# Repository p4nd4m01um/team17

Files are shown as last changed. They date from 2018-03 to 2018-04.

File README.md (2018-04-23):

dei cing 2
========

## Motivation
In the winters of Glasgow, our team found roads always icy and slippery. Some people slip on roads because of ice and snow. So we decided to construct a system to prevent these accidents.
  
## Target
This project aims to prevent the formation of ice or snow by using brine as the anti-icing agent. Utilising the humidity and temperature sensor to detect the environmental conditions, the sprinkler spreads the brine water which is controlled by Raspberry Pi. IR sensor is used to detect people and animals. When it detects people, the sprinkler turns off.  

## Setup
<p align="center">
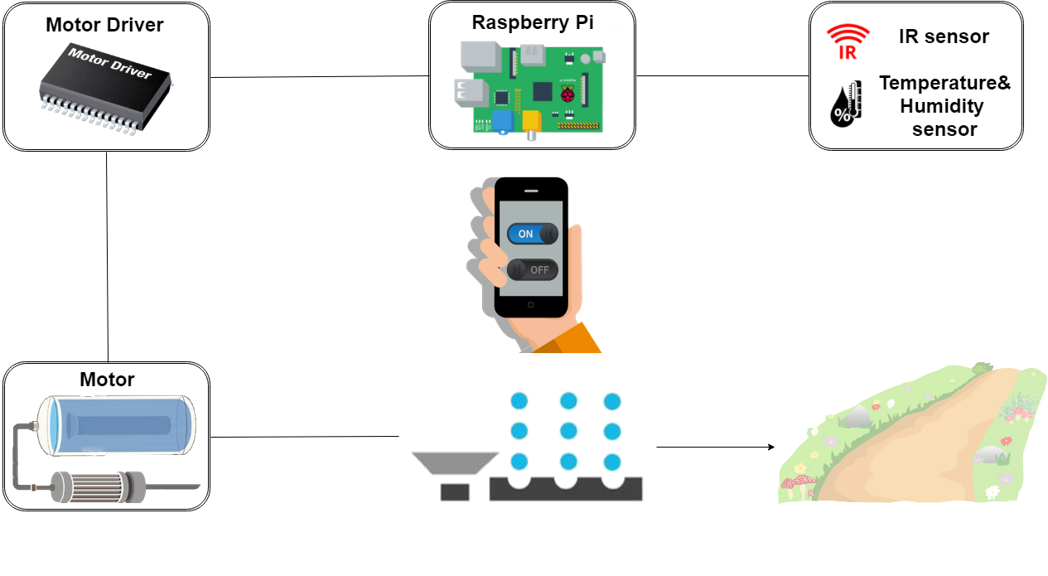
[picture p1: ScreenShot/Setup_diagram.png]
 
</p>

## Flow Diagram
<p align="center">
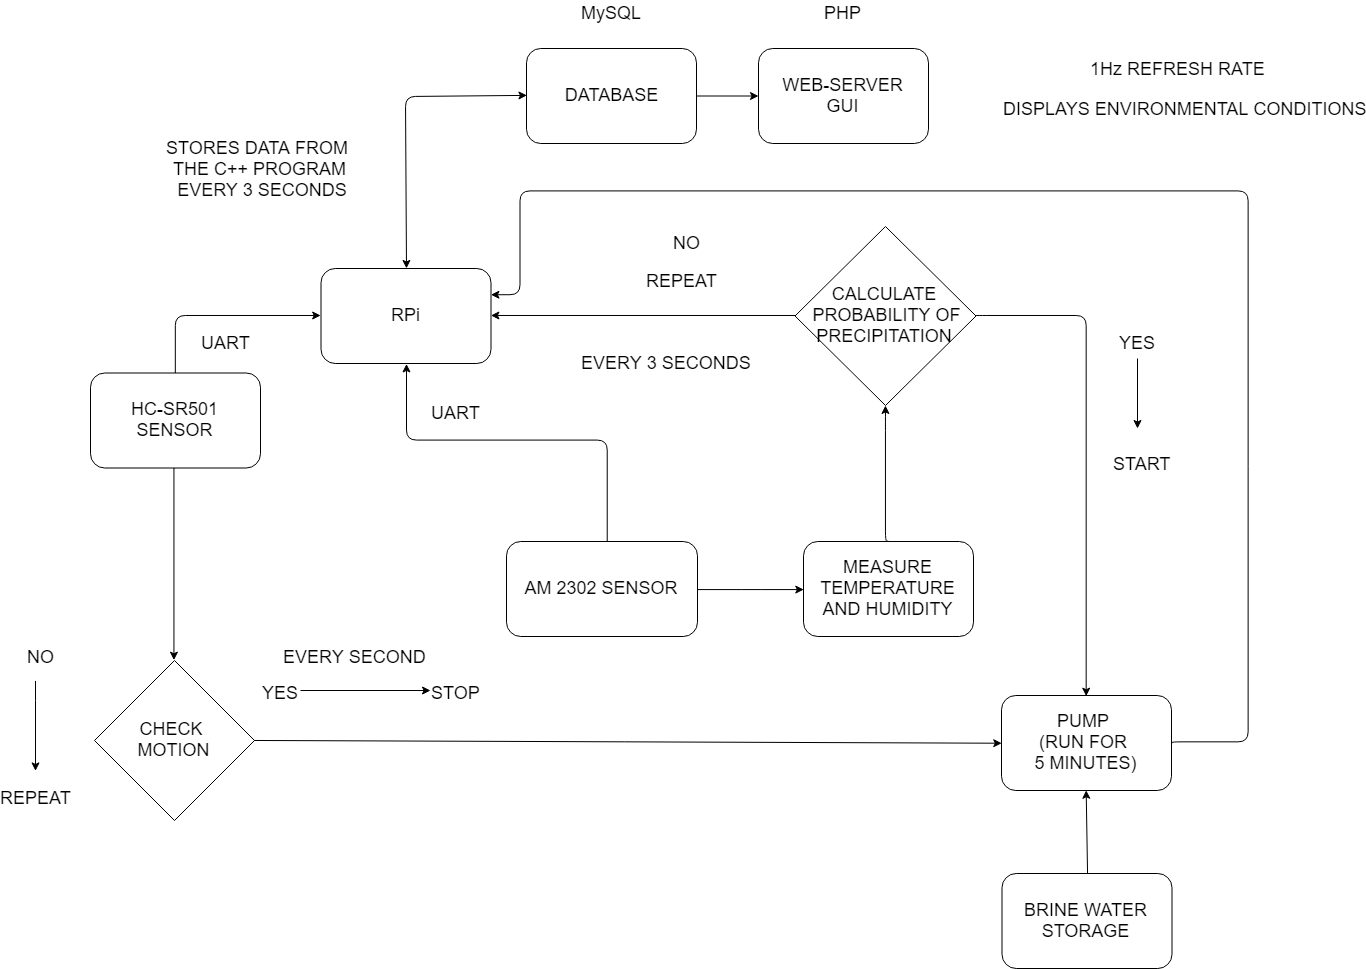
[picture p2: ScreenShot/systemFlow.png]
 
  
***

## Components

**1. _IR sensor: HC-SR501 PIR Motion Detector_**  
- Voltage: 5V – 20V  
- Power Consumption: 65mA  
- TTL output: 3.3V, 0V  
- Lock time: 0.2 sec  
- Trigger methods: L – disable repeat trigger, H enable repeat trigger  
- Sensing range: less than 120 degree, within 7 meters  
- Temperature: – 15°C ~ +70°C  
- Dimension: 32*24 mm, distance between screw 28mm, M2, Lens dimension in diameter: 23mm

<p align="center">
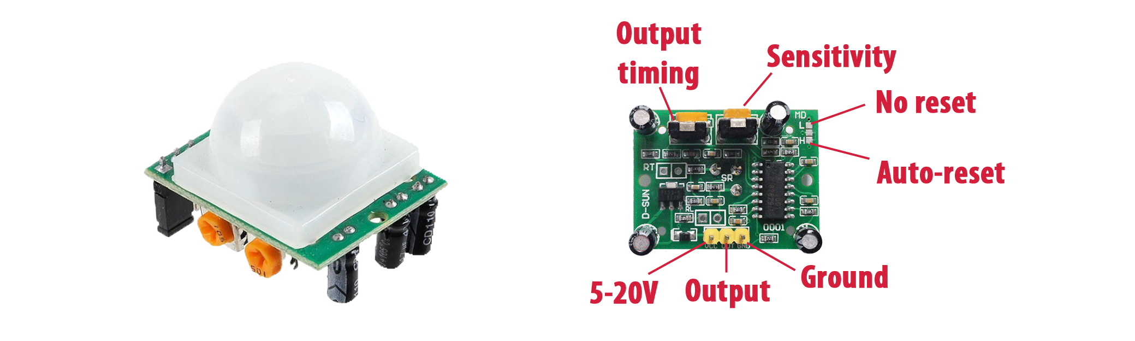
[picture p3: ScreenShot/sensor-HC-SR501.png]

</p>

**2. _Humidity and temperature sensor: DHT22(AM2302)_**
- Low cost  
- 3 to 5V power and I/O  
- 2.5mA max current use during conversion (while requesting data)  
- Good for 0-100% humidity readings with 2-5% accuracy  
- Good for -40°C to 80°C temperature readings ±0.5°C accuracy  
- No more than 0.5 Hz sampling rate (once every 2 seconds)  
- Single-bus data is used for communication between MCU and DHT22, it costs 5ms for single time
communication.  

<p align="center">
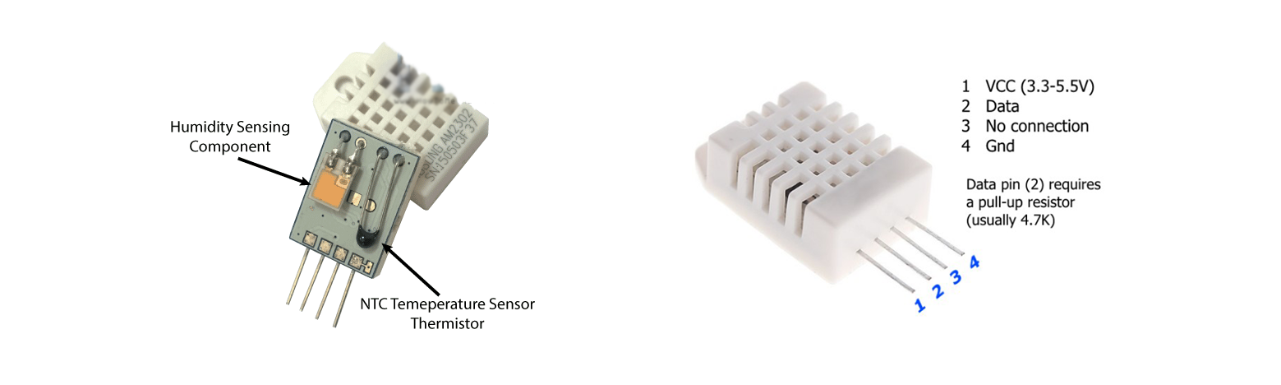
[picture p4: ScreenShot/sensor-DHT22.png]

</p>

**3. _Brushless DC Motor Pump Decdeal QR50E_**
- Low cost and Versatile
- 12V 5W Rating
- 280l/H pump quantity
- can handle different types of solutions including salt water (brine) and oil at various temparatures

<p align="center">
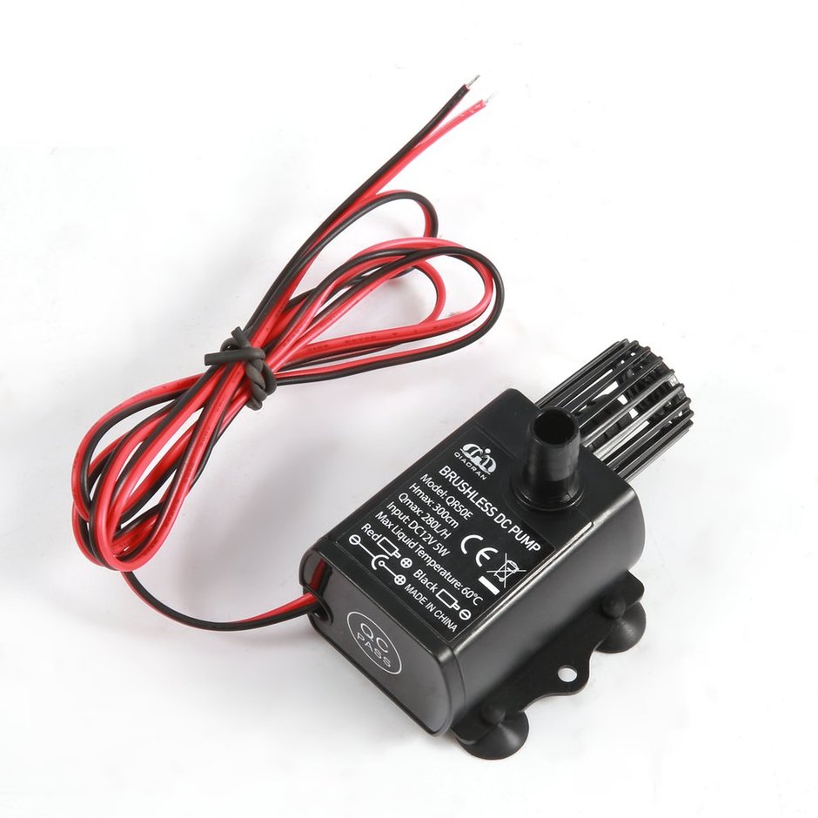
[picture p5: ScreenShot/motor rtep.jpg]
  
</p>

## How to implement code  
1. Clone the repository.
2. Copy the Code/html to /var/www/html
3. In the Code folder, the main file can be executed.
4. If you changed the input/output pin number, you can use CMake to rebuild the main file.
5. Open browser enter the address of raspberryPi to access the user interface. 

## More information in [WIKI](https://github.com/p4nd4m01um/team17/wiki)  
## Criteria for assessment： [Criteria](https://github.com/p4nd4m01um/team17/blob/master/Criteria.md)
  
# YouTube Video:
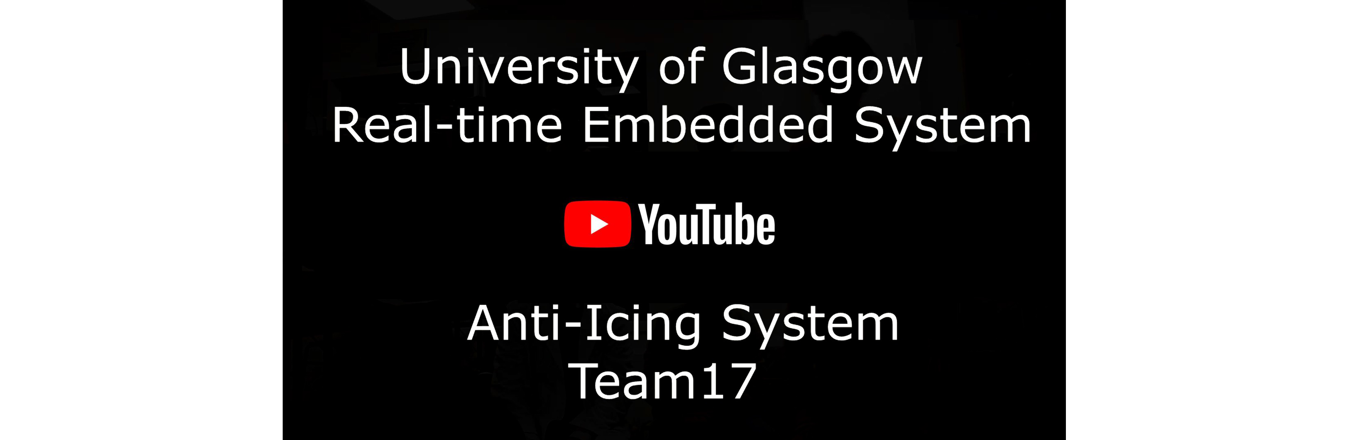
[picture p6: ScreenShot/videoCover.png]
(http://www.youtube.com/watch?v=QaHXD64GoVk "")


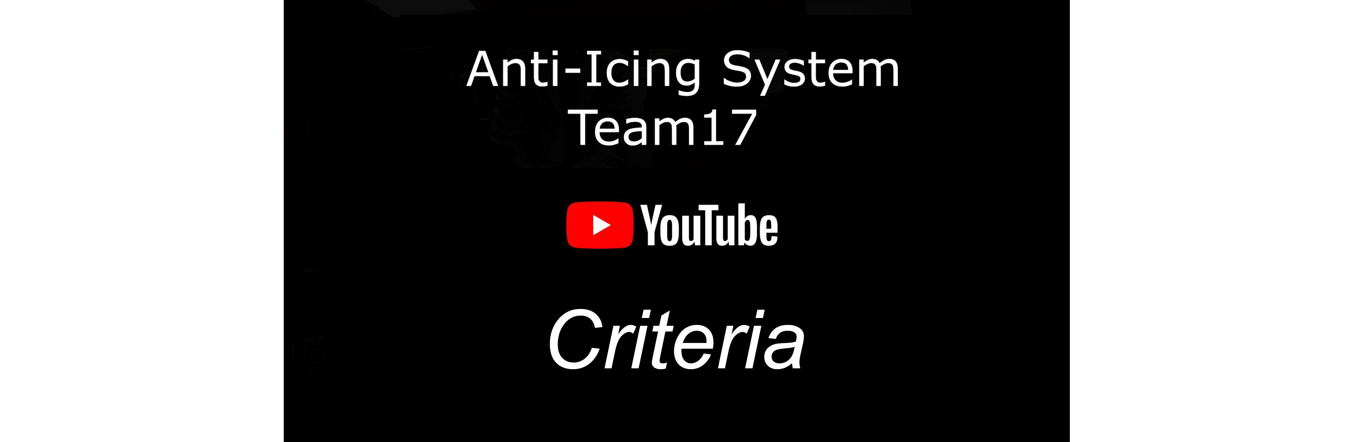
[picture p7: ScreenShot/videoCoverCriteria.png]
(http://www.youtube.com/watch?v=q8ZnzTlgLoI "")


## University of Glasgow

Course name Real Time Embedded Programming, in association with University of Glasgow.  
Course convener: Dr. Bernd Porr

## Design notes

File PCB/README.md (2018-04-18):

# PCB description  

## Schematic and PCB   
We selected Orcad capture and PCB editor to draw the PCB. 
#### sensors circuit:   
The original file of the [schematic](https://github.com/p4nd4m01um/team17/blob/master/PCB/Sensor%20circuit.zip).  Please open this file by Orcad Capture.  
The original file of the [PCB](https://github.com/p4nd4m01um/team17/blob/master/PCB/Circuit%20for%20sensors.brd). Please open this file by PCB Editor.   
  
### Here is the schematic of sensors circuit. 16 pins are enough for our project, so we only used a header with 16 Pins.   
J2 is for PIR sensor  
J3 is for humidity&temperature sensor   
J4 is for GPIO  
R1 and R2 are the pull-up resistors   
D1 LED is for the motor test. This signal is used to control motor.  
D2 LED is for observation. It will show if the circuit is working.    
sensor circuit    
  
### The PCB layout is shown in the next figure.  
sensor pcb layout     
    
### Here is the pdf file for fabrication. This one is the top layer.  
sensor pcb top      
  
### Here is the bottom layer.  
sensor pcb    
  
### The real view  

</p>

---    
### Schematic and PCB for motor drive  

#### motor control circuit:  
The original file of the [schematic](https://github.com/p4nd4m01um/team17/blob/master/PCB/Motor%20control%20circuit.zip).  Please open this file by Orcad Capture.  
The original file of the [PCB](https://github.com/p4nd4m01um/team17/blob/master/PCB/Motot%20control.brd). Please open this file by PCB Editor.  
### Here is the Schematic of Motor driver circuit. 
J1 is for Power source.  
J2 is for Motor.  
J3 is for Control signal that comes from the GPIO.  
J4 is for switch.  
Q1 is to control the motor.  
D2 LED is to check if the circuit works properly.  
motor circuit  

### The PCB layout is shown in the next figure.  
motor pcb layout  

### Here is the pdf file for fabrication. This one is the top layer.  
motor pcb top  
  
### This one is the bottom layer.  
motor pcb bottom  
  
### The real view  

</p>

  #### PCB Artwork  
   PCB Artwork in the circuit designing process refers to the planning and placing of electrical traces and via holes to connect every component mounted on the board with each other.  
   PCB Artwork rules/guidelines is used as a base for the circuit design to facilitate a standard design and manufacturing procedures.
   this file named as ``` art_parm.txt ``` .
    
  #### PCB NC  
   Named as ``` nc_param.txt ```.  
     
  #### IPC2581  
  IPC-2581 is a generic standard for printed circuit board and assembly manufacturing description data and transfer methodology.  
  This file named as ``` ipc2581.txt```.

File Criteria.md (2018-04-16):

# Criteria

**_1. Assessment of responsiveness of the application in the context of the task._**
 
Since the environmental changes aren’t very drastic, slow response is perfectly acceptable. Our system does not have any major latency (0.022 seconds to 5 ms approx.) impeding the purpose of the tasks it has to perform. Thus, proving to be quite an effective solution.
 
_**2. Overall latency between the physical event and output**_

Approximately 3 to 4 second delay between the web server and physical event is found to exist. Since the speed of the response doesn’t take a high precedence in the application of our system, we can easily work with the existing latency in the system. It must also be noted that the responsive action is instantaneous, whereas the display of information on the web server has latency. 

The sensors have a processing latency of about 0.022 seconds to 5ms. Thus, it does not affect the performance of the system.

_**3. What is the sampling rate?**_
 
We use 2 sensors. 

* PIR sensor: which has a sampling rate of 1 second    
* Temperature & Humidity sensor: sampling rate of 3 seconds

The sampling of the data from the C++ program to the mySQL database occurs every 3 seconds

The PHP web server reads data from the database every second

_**4. Bus protocols:**_
 
The sensors come with a support for various bus protocols. But, we prefer to use UART (Universal Asynchronous Receiver-Transmitter) as we can use 1 Data bus to achieve our requirements and also, due to the simplicity in programming it. The 40-bit data response signal from Temperature sensor is given in the wiki.

Single-bus data is used for communication between RPI and DHT22, it costs 5ms for single time communication. This is a latency caused due to data processing.
 
_**5. How many channels?**_

A total number of 3 channels were ussed for the project. Namely:
* Motor
* PIR sensor
* Temperature and Humidity sensor
 
_**6. Low level implementation:**_

Userspace is used. Because:

* To implement GUI (Web-Server).
* Coding is easier.
* Fast response of the system is not an issue.
 
_**7. Data flow is provided in the detailed control flow graph section in the wiki.**_

[Detailed Control Flow Graph of the System](https://github.com/p4nd4m01um/team17/wiki/Detailed-Control-Flow-Graph-of-the-System)

_**8. Buffering of Data: How many samples?**_

We do not use a buffer as it is not necessary for a project of this scale. However, we use a database to store the obtained data from the sensors before the website reads it. The website reads the stored data every 3 seconds from the MySQL database.

_**9. Buffering:**_

No buffer is used, as we do not have a large amount of data that needs to undergo post-processing procedures and data trend analysis. However, since data from the temperature and humidity sensor is a string of 40 bits, it will only output temperature and humidity value after serially processing the entire string of 40 bits of data. Thus, we have added a timer and timed the latency resulting from it.

Latency due to buffering:
* No latency is resulted from the sensor buffer. 
* When a timer is added and the latency is timed, a latency of 0.022 seconds to 5 ms  was resulted from the temperature and humidity sensor.
 
_**10. Post Processing of data:**_

No latency due to post-processing is resulted as we are using only BLDC motor pump as an output, whose response is instantaneous. thus N/A.
 
_**11. How many threads are used:**_

4 threads have been used.
* Main works on one thread.
* Both the sensors work on their own independent threads.
* The web server runs on its own thread.

_**12. GUI:**_
 
The web-server is written in PHP using jQuery and Ajax which is short for asynchronous JavaScript and XML. It reads data from the database every second (which doubles up as the refresh rate of the website).  
 
_**13. Structure of the software:**_

The software structure has a low coupling design. We are using MySQL database as a medium for data storing and reading. One class called MyDB which manipulates MySql database by using SQL syntax. Another class called Sensor which involves relevant variables and reading functionalities for Temperature and Humidity sensor and PIR sensor. The main function calls the sensor functions for retrieving data and then stores the data into the database. The web server read the data from Mysql database. The task of controlling the motor pump is accomplished through PHP(web server).

_**14. Roles in the team:**_
 
_Revanth Kailashnath:_
* Github maintenance and updates including licenses, readme, wiki and code
* Technical content writing including criteria of assessment
* Procuring Hardware and sensor selection
* Motor control circuit, PCB designs and soldering
* Hardware implementation
* Mathematical equation for finding RHthreshold
* Package Version numbering and release
* Release strategy formulation
* Publications in various electronic blogs and websites including hackaday, hackster, instructables, reddit/r/diy

_Jinyu Cao:_
* Github Readme.md
* Procuring Hardware and sensor selection
* sub function for sensors
* PCB designs for sensors and motor
* PCB fabrication, soldering and test
* Unit test 
* Videography

_Hao Ding:_
* Code of Temperature & Humidity sensor
* Code of IR sensor
* Code of Snow calculation
* Code of MySql connection
* Building MySql database
* Building Web server
* Php code for data connection
* User interface design
* Applying domain name for public accessibility
* WIKI layout
* Video editing

_**15. Time allocation:**_
 
* Software: 2 months
* Hardware: 1 month
* Mechanical setup:10 days
 
_**16. Version Control Software and numbering of releases/ milestones:**_

Git as it is free. GitHub has a wide popularity in the technogeek community. It is easy to log, maintain and very efficient to use.
A project with only one branch(master) was used with accomodating and sensible distribution of various tasks among the team members. V 1.0 was released on the 16th of April, 2018 to mark the milestone of initial release of the product. later versions will be released based on the performance and iff tweaking is necessary.

_**17. Release strategy:**_

Publication in various social media and mainstream electronic websites, including:

* Hackster:  https://www.hackster.io/vant4u/anti-icing-system-440a41
* Instructables:  https://www.instructables.com/id/Anti-Icing-System/
* reddit/r/diy:  https://www.reddit.com/r/raspberry_pi/comments/8coow3/antiicing_system_using_raspberry_pi/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
* Submitted the project to hackaday (waiting for them to revert back)
* create YouTube videos: 	https://www.youtube.com/watch?v=QaHXD64GoVk  
  				https://www.youtube.com/watch?v=q8ZnzTlgLoI

_**18. Measurement of success:**_

We will consider the project to be a success if it can prevent the formation of ice (precipitation) on pavements. Seeing as its accomplished this mission, the contraption can be declared to be a success. 
We will update you the success story by the end of the course duration.

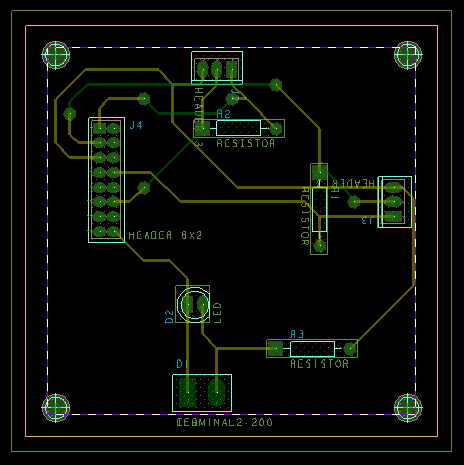
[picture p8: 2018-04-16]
ScreenShot/schematic_2.PNG

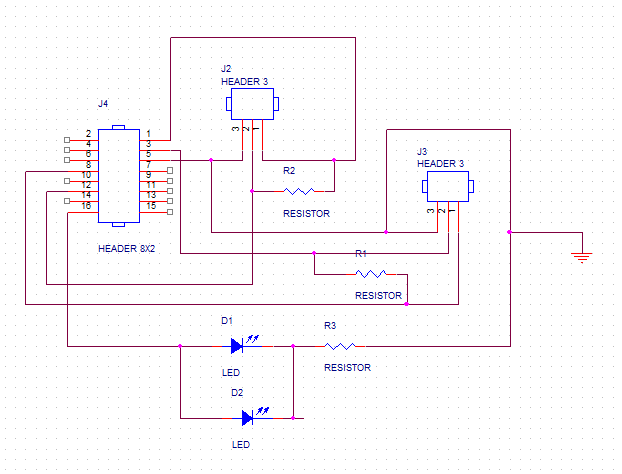
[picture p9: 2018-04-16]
ScreenShot/schematic_1.PNG

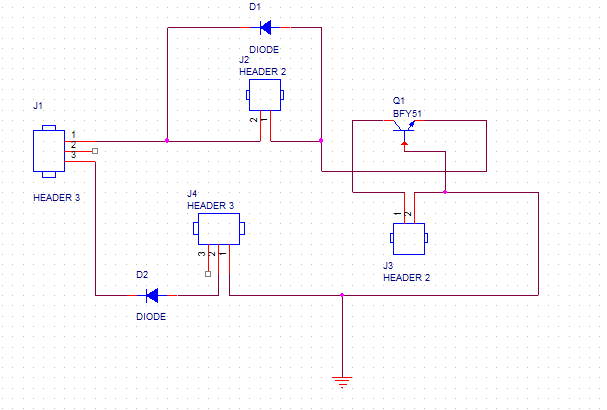
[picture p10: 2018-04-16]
ScreenShot/schematicMotor.PNG

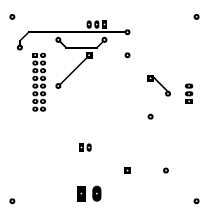
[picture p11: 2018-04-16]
ScreenShot/pcbTopLayer.PNG

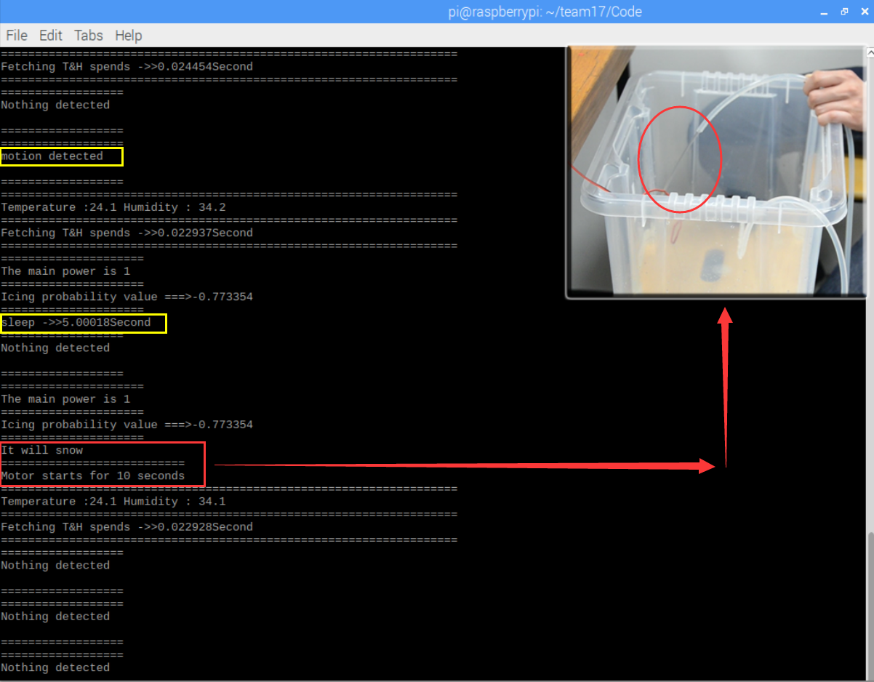
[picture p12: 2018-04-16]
ScreenShot/powerOn.png

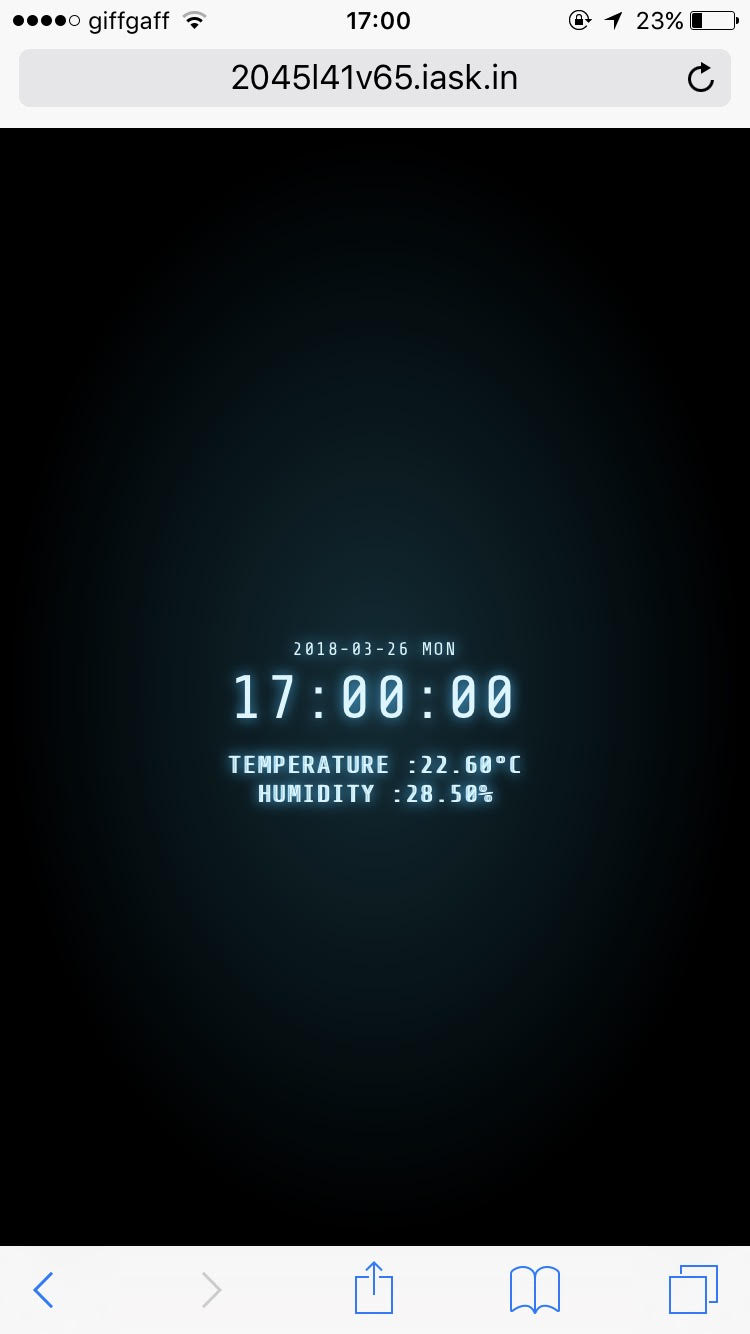
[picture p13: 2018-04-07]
ScreenShot/web-phone.jpg

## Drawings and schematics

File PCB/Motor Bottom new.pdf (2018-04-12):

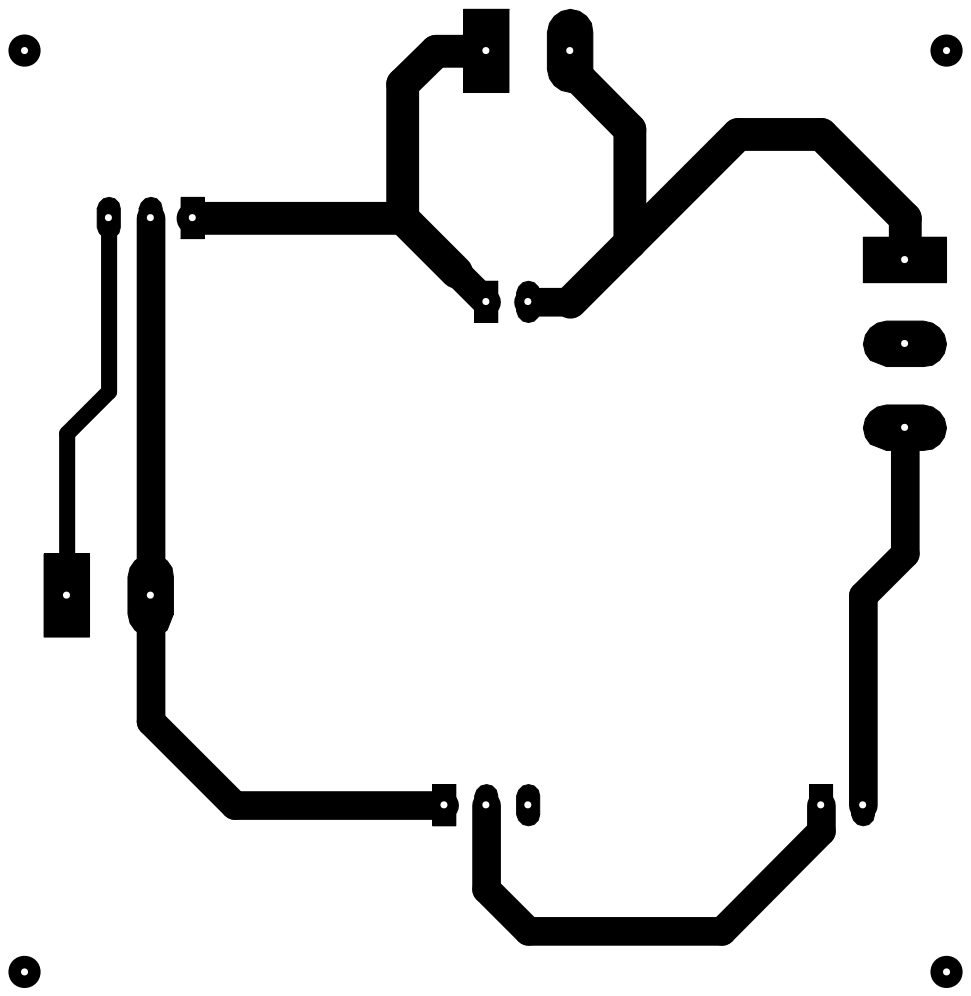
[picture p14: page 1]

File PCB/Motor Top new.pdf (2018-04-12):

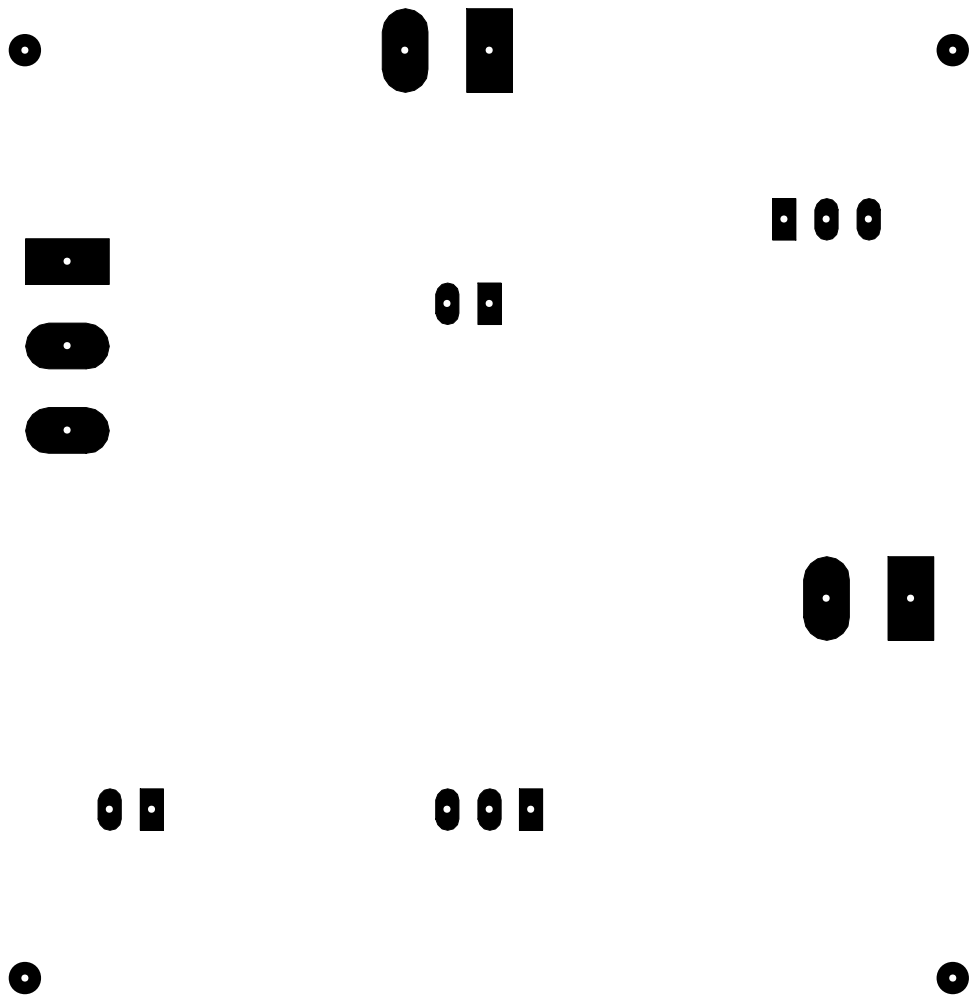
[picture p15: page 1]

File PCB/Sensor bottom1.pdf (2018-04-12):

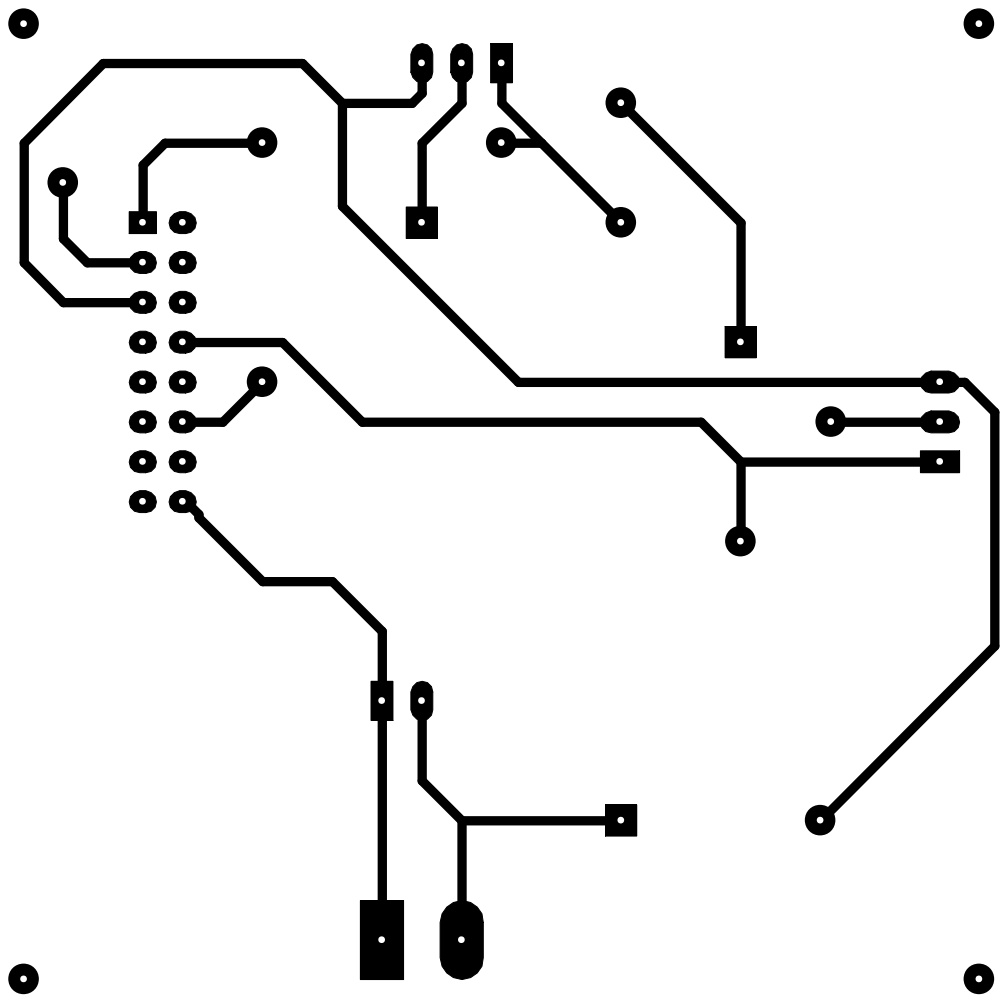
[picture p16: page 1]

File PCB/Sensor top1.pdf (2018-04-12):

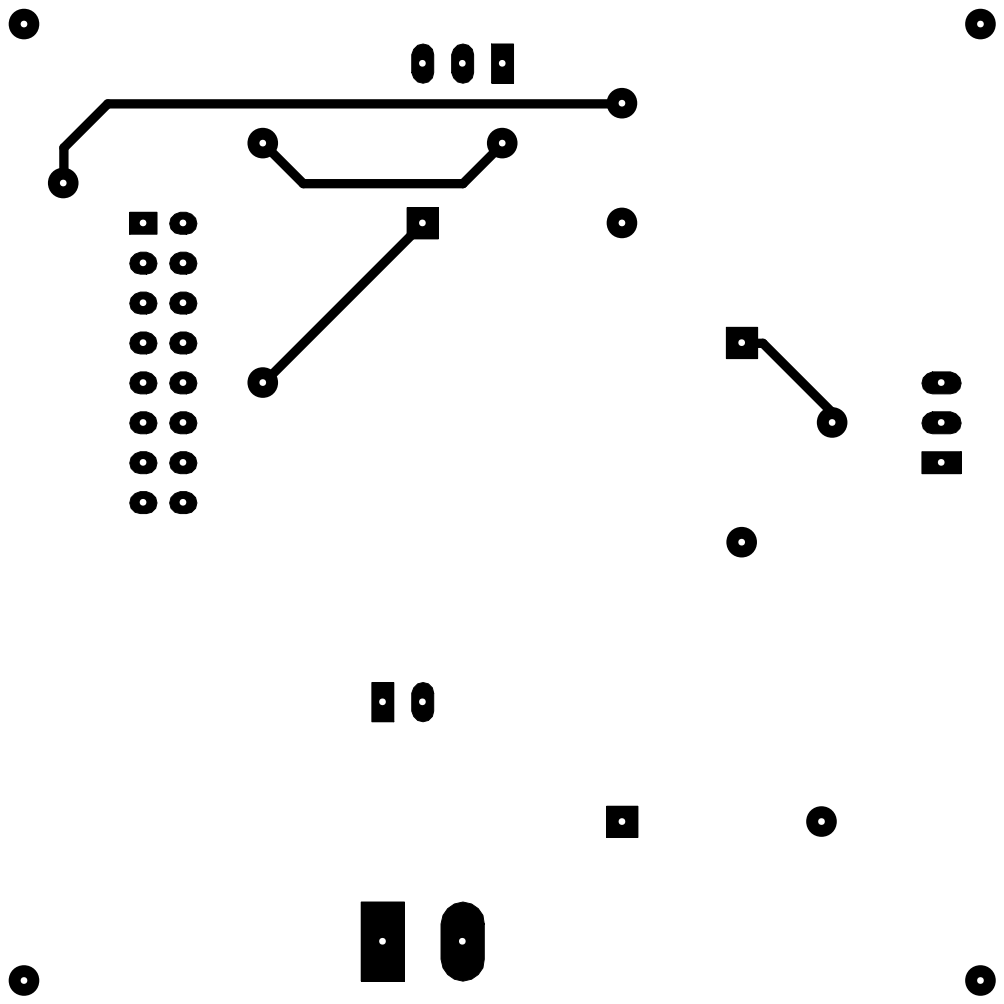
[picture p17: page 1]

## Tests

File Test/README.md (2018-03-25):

## Sensors  
### Humidity and Temperature sensor:   
we choose DHT22 with one signal output.  
- Low cost  
- 3 to 5V power and I/O  
- 2.5mA max current use during conversion (while requesting data)  
- Good for 0-100% humidity readings with 2-5% accuracy  
- Good for -40 to 80°C temperature readings ±0.5°C accuracy  
- No more than 0.5 Hz sampling rate (once every 2 seconds)  

- Single-bus data is used for communication between MCU and DHT22, it costs 5mS for single time
communication.  

### PIR sensor:
we choosed HC-SR501.

- Voltage: 5V – 20V  
- Power Consumption: 65mA  
- TTL output: 3.3V, 0V  
- Lock time: 0.2 sec  
- Trigger methods: L – disable repeat trigger, H enable repeat trigger  
- Sensing range: less than 120 degree, within 7 meters  
- Temperature: – 15 ~ +70  
- Dimension: 32*24 mm, distance between screw 28mm, M2, Lens dimension in diameter: 23mm  

## connection:  
### PIR sensor  
connect ground to Header 6  
Vcc to Header 2  
signal to Header 11  
LED to Header 13  
  
### Humidity&temperature sensor  
connect ground to Header 6  
Vcc to Header 4  
signal to Header 7 

## Test Code  

- the code for testing DHT22 was named as humidityandtemp.c
- the code for testing Hc-SR501 was named as PIR_sensor.c

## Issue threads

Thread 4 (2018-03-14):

How is that measured and deemed to be successful?

JiananKan, 2018-03-14:
If other things such as vehicles go through the road, will the sprinkler turn off? If it is turn off, is that mean it can not work in the car park?

team 6

Cao-Jinyu, 2018-03-14:
Our project is mainly on the pavement. In most circumstance, ice or snow in the rode will melt because of the car pressure.

Closed 2018-03-15.

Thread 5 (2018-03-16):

Fabrication and testing?

acra6488, 2018-03-16:
Hi, Could we see how testing and fabrication is going, via some notes or images, or a social media page?
-Aurelie -Team 2

p4nd4m01um, 2018-03-18:
we will do this in the future, but as of now, the sensors have been tested as a standalone system, they're yet to be coupled with the motor circuit and tested as a whole

p4nd4m01um, 2018-03-21:
the PCB schematics and design files should give you the overall idea of the ongoing progress of the project

kenzo0619, 2018-03-26:
Since the PCB still in the process, we cannot perform an entire system test. However, we used LED light to simulate the motor trigger, it works well. The main program and web interface were tested with examples as can be found in the Test demonstration page of WIKI.
The unit test of our project would be done in time.

Closed 2018-03-26.

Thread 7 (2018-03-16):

Missing components

SimoneMarcigaglia, 2018-03-16:
What motor/motor driver would you be using and how would you control it with the raspberry Pi?

Team 3

p4nd4m01um, 2018-03-18:
currently we are using a transistor switch to control the motor. it is a micropump manufactured by RS components. the wiki project description would give you a better idea about component specifications. hope this answers your question :)

Closed 2018-03-21.

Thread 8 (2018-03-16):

Missing circuit schematics

SimoneMarcigaglia, 2018-03-16:
Cannot find the circuit schematics and pcb design anywhere.

- Team 3

p4nd4m01um, 2018-03-18:
you can find it in the folder titled, PCB.

p4nd4m01um, 2018-03-21:
there are 2 PCB design circuits. one for the motor transistor switch control and the other to connect all the external components out the RPi GPIOs

Closed 2018-03-21.

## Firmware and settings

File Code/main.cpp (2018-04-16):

#include<iostream>
#include"MySql/MyDB.h"
#include"Sensor/sensor.h"
#include<wiringPi.h>
#include<thread>
#include<cmath>
#include<string>
#include<unistd.h>

using namespace std;

int main(){

	sensor s1;
	MyDB db;
	db.initDB("localhost", "pi", "", "sensor");



	if(wiringPiSetup()==-1){
		exit(1);
	}


	thread t1(&sensor::readIrSensor, &s1); // thread 1 -- read IR sensor
	t1.detach();

	thread t2(&sensor::readTempHumSensor, &s1); // thread 2 -- read temperature and humidity sensor
	t2.detach();


	while(1){

		sleep(3);
		db.update(s1.getTemp(),s1.getHum()); // update the the data into database
		s1.snowCal();	//run calculator and trigger

	}

	return 0;


}

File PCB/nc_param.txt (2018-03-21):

INTEGER-PLACES         2
DECIMAL-PLACES         5
X-OFFSET               0.000000
Y-OFFSET               0.000000
FEEDRATE               1
COORDINATES            ABSOLUTE
OUTPUT-UNITS           ENGLISH
TOOL-ORDER             INCREASING
REPEAT-CODES           YES
SUPPRESS-LEAD-ZEROES   NO
SUPPRESS-TRAIL-ZEROES  NO
SUPPRESS-EQUAL         NO
TOOL-SELECT            NO
OPTIMIZE_DRILLING      NO
ENHANCED_EXCELLON      NO
HEADER                 none
LEADER                 12
CODE                   ASCII
SEPARATE               NO
SEPARATE-ROUTING       NO
DRILLING               LAYER-PAIR
BACKDRILL              NO
CAVITY                 NO
COUNTER                NO
TOLERANCE_DRILL        YES
TOLERANCE_TRAVEL       YES
TOOL_SIZE              YES
ROTATION               YES
NON_STANDARD           YES
TOTAL_DRILL            NO
SEPARATE_SLOT          NO
SUPPRESS_TOLERANCE     YES
SUPPRESS_TOOLSIZE      YES
SUPPRESS_ROTATION      YES

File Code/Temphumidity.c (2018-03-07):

#include<wiringPi.h>
#include<stdio.h>
#include<stdlib.h>
#include<stdint.h>

#define MAX_TIME 100
#define DHT11PIN 7 //读取数据引脚
#define ATTEMPTS 5 //retry 5 times when no response
int dht11_val[5]={0,0,0,0,0};

int dht11_read_val(){
uint8_t lststate=HIGH; //last state
uint8_t counter=0;
uint8_t j=0,i;
for(i=0;i<5;i++)
dht11_val[i]=0;
//host send start signal
pinMode(DHT11PIN,OUTPUT); //set pin to output 
digitalWrite(DHT11PIN,LOW); //set to low at least 18ms 
delay(18);
digitalWrite(DHT11PIN,HIGH); //set to high 20-40us
delayMicroseconds(30);
//start recieve dht response
pinMode(DHT11PIN,INPUT); //set pin to input
for(i=0;i<MAX_TIME;i++)
{
counter=0;
while(digitalRead(DHT11PIN)==lststate){ //read pin state to see if dht responsed. if dht always high for 255 + 1 times, break this while circle
counter++;
delayMicroseconds(1);
if(counter==255)
     {
     break;
     }
}
lststate=digitalRead(DHT11PIN); //read current state and store as last state. 
if(counter==255) //if dht always high for 255 + 1 times, break this for circle
break;
// top 3 transistions are ignored, maybe aim to wait for dht finish response signal
if((i>=4)&&(i%2==0)){
dht11_val[j/8]<<=1; //write 1 bit to 0 by moving left (auto add 0)
if(counter>16) //long mean 1
dht11_val[j/8]|=1; //write 1 bit to 1 
j++;
}
}
// verify checksum and print the verified data
if((j>=40)&&(dht11_val[4]==((dht11_val[0]+dht11_val[1]+dht11_val[2]+dht11_val[3])& 0xFF))){
float f, h;
h = dht11_val[0] * 256 + dht11_val[1];
h /= 10;
f = (dht11_val[2] & 0x7F)* 256 + dht11_val[3];
f /= 10.0;
if (dht11_val[2] & 0x80) f *= -1;
printf("Temp = %.1f *C, Hum = %.1f \%\n", f, h);
return 1;
}
else
return 0;
}


int main(void){
//int attempts=ATTEMPTS;
if(wiringPiSetup()==-1)
exit(1);
  
  while(1){
   dht11_read_val();
    delay(3000);
  }
//while(attempts){ //you have 5 times to retry
//int success = dht11_read_val(); //get result including printing out
//if (success) { //if get result, quit program; if not, retry 5 times then quit
//break;
//}
//attempts--;
//delay(3000);
}
return 0;
}

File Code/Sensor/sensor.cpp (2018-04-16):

#include"sensor.h"

sensor::sensor(){		//constructor sets pin mode when the object is created.

	pinMode(MOTOR_PIN, OUTPUT);
	pinMode(POWER_PIN,INPUT);
	pinMode(PIR_PIN, INPUT);

}

void sensor::readIrSensor(){


	while(1){

		sleep(1);

		this->pow = digitalRead(POWER_PIN); //read the main power circumstance (whether user trun on/off the toggle) 

		if (this->pow == 1){

			this->ir = digitalRead(PIR_PIN); //read PIR sensor pin value

			if (this->ir==1){

				cout<<"=================="<<endl;
				cout<<"motion detected \n"<<endl;
				cout<<"=================="<<endl;

				digitalWrite(MOTOR_PIN, LOW); //stop the motor

				this->irDetect = true; // true on the detected value (the temperature & humidity sensor stop working )

				auto startIr = system_clock::now();
				sleep(5);		//stop for 5 second for pedestrian pass through.
				this->irDetect = false;
				auto endIr = system_clock::now();
                       		auto durationIr = duration_cast<microseconds>(endIr - startIr);
                       		cout<<"sleep ->>"<<double(durationIr.count()) * microseconds::period::num/microseconds::period::den<<"Second"<<endl;

			}

			else{
				cout<<"=================="<<endl;
				cout<<"Nothing detected\n"<<endl;
				cout<<"=================="<<endl;

			}
		}

	}

}

void sensor::readTempHumSensor(){

	while(1){

		auto start = system_clock::now();
		uint8_t lststate = HIGH; //last state
		uint8_t counter = 0;
		uint8_t j = 0, i;

		for(i=0; i<5; i++){
			this->data_tempHumSensor[i] = 0;
		}

		//host send start signal
		pinMode(DHT22_PIN,OUTPUT); //set pin to output
		digitalWrite(DHT22_PIN,LOW); //set to low at least 18ms
		delay(18);
		digitalWrite(DHT22_PIN,HIGH); //set to high 20-40us
		delayMicroseconds(30);
		//start recieve dht response
		pinMode(DHT22_PIN,INPUT); //set pin to input

		for(i=0; i<MAX_TIME; i++){

			counter=0;
			while(digitalRead(DHT22_PIN) == lststate){
			 //read pin state to see if dht responsed. if dht always high for 255 + 1 times, break this while circle
				counter++;
				delayMicroseconds(1);
				if(counter == 255){
	     				break;
     				}

			}

			lststate = digitalRead(DHT22_PIN); //read current state and store as last state. 
			if(counter == 255){ //if dht always high for 255 + 1 times, break this for circle

				break;
			}

			// top 3 transistions are ignored, maybe aim to wait for dht finish response signal
			if((i >= 4)&&(i%2 == 0)){
				this->data_tempHumSensor[j/8]<<=1; //write 1 bit to 0 by moving left (auto add 0)
				if(counter > 16) //long mean 1
				this->data_tempHumSensor[j/8]|=1; //write 1 bit to 1 
				j++;
			}
		}

		// verify checksum and print the verified data
		if((j>=40)&&(this->data_tempHumSensor[4]==((this->data_tempHumSensor[0] +
							    this->data_tempHumSensor[1] +
							    this->data_tempHumSensor[2] +
							    this->data_tempHumSensor[3]) & 0xFF))){

			this->data_hum = this->data_tempHumSensor[0] * 256 + this->data_tempHumSensor[1];
			this->data_hum /= 10;
			this->data_temp = (this->data_tempHumSensor[2] & 0x7F)* 256 + this->data_tempHumSensor[3];
			this->data_temp /= 10.0;

			if (this->data_tempHumSensor[2] & 0x80){
				this->data_temp *= -1;
			}

			auto end = system_clock::now();
			auto duration = duration_cast<microseconds>(end - start);
			cout<<"==================================================================="<<endl;
			cout<<"Temperature :"<< this->data_temp<<" Humidity : "<< this->data_hum<<endl;
			cout<<"==================================================================="<<endl;
			cout<<"Fetching T&H spends ->>"<<double(duration.count()) * microseconds::period::num/microseconds::period::den<<"Second"<<endl;
			cout<<"==================================================================="<<endl;
			sleep(3); //sleep for 3 seconds and then start for next data fetching.


		}

	}
}

void sensor::snowCal(){

	// this is a equation which produces a icing probability with the given temperature and humidity values.
	this->data_reHum = 9.5 * exp((-17.27*this->data_temp)/(this->data_temp + 238.3))*(10.5 - this->data_temp);
	this->data_snowPro = this->data_reHum/this->data_hum;

	cout<<"====================="<<endl;
	cout<<"The main power is "<<this->pow<<endl;
	cout<<"====================="<<endl;
	cout<<"Icing probability value ===>"<<this->data_snowPro<<endl;
	cout<<"====================="<<endl;

	this->pow = digitalRead(POWER_PIN);

	if (this->pow ==1){

		//The threshould we set "0.9" 
		//This means when the calculator yields a probability great than 90%, it works.
		
		if (this->data_snowPro <= 0.9 && this->irDetect == false){

			cout<<"It will snow"<<endl;

			digitalWrite(MOTOR_PIN, HIGH);
			cout<<"==========================="<<endl;
			cout<<"Motor starts for 10 minutes"<<endl;
			sleep(600);

			cout<<"==========================="<<endl;
			cout<<"Motor stops for 6 hours"<<endl;
			digitalWrite(MOTOR_PIN,LOW);
			sleep(21600); //stop working for 6 hours

			cout<<"============================"<<endl;
			cout<<"Trigger starts working again"<<endl;
			cout<<"============================"<<endl;
		}
		else{
			digitalWrite(MOTOR_PIN, LOW);
		}

	}
}

float sensor::getTemp(){

	return this->data_temp;
}

float sensor::getHum(){

	return this->data_hum;
}

float sensor::getSnowPro(){

	return this->data_snowPro;
}

float sensor::getReHum(){

	return this->data_reHum;
}

int sensor::getIr(){

	return this->ir;
}

bool sensor::getPow(){

	return this->pow;
}

void sensor::getIrDetect(bool input){

	return this->irDetect;
}

void sensor::setTemp(float input){

	this->data_temp = input;
}

void sensor::setHum(float input){

        this->data_hum = input;
}

void sensor::setSnowPro(float input){

        this->data_snowPro = input;
}

void sensor::setReHum(float input){

        this->data_reHum = input;
}

void sensor::setIr(int input){

	this->ir = input;
}
void sensor::setPow(bool input){

	this->pow = input;
}
void sensor::setIrDetect(bool input){

	this->irDetect = input;
}

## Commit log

2018-03-07 modified PIR sensor code
2018-03-10 multiple threads read and write date
2018-03-12 Rename Code/testt.c to Code/Humidity-temperature Test/testt.c
2018-03-12 Update and rename Code/Temphumidity.c to Code/Humidity-temperature Test/Temphumidity.c
2018-03-12 ir sensor
2018-03-14 main function done with test GPIO pin
2018-03-16 Create pcb
2018-03-25 Added rtep detailed flow chart(1).jpg
2018-03-25 test humidity&temperature sensors
    this code is used to test humidity and temperature sensor
2018-03-25 Fro testing PIR sensor
    The sensor is HC SR51
2018-04-04 Motor power supply
2018-04-12 timer and switch button
2018-04-12 switch for php
2018-04-14 switch logic
